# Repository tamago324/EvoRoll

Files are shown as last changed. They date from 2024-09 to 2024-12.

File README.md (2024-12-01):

# EvoRoll

左側を haqua34、右側を EvoRoll として使うことを想定している

> NOTE: KiCad 7 を使用しています

## [v1](v1/README.md)

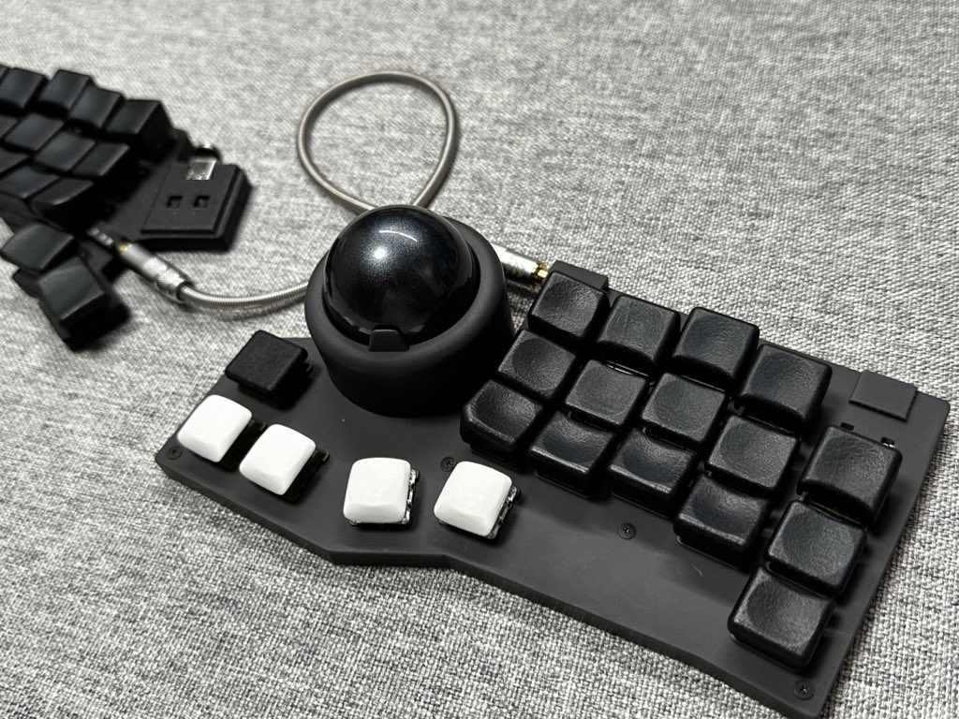
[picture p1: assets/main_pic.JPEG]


## [v2](v2/README.md)

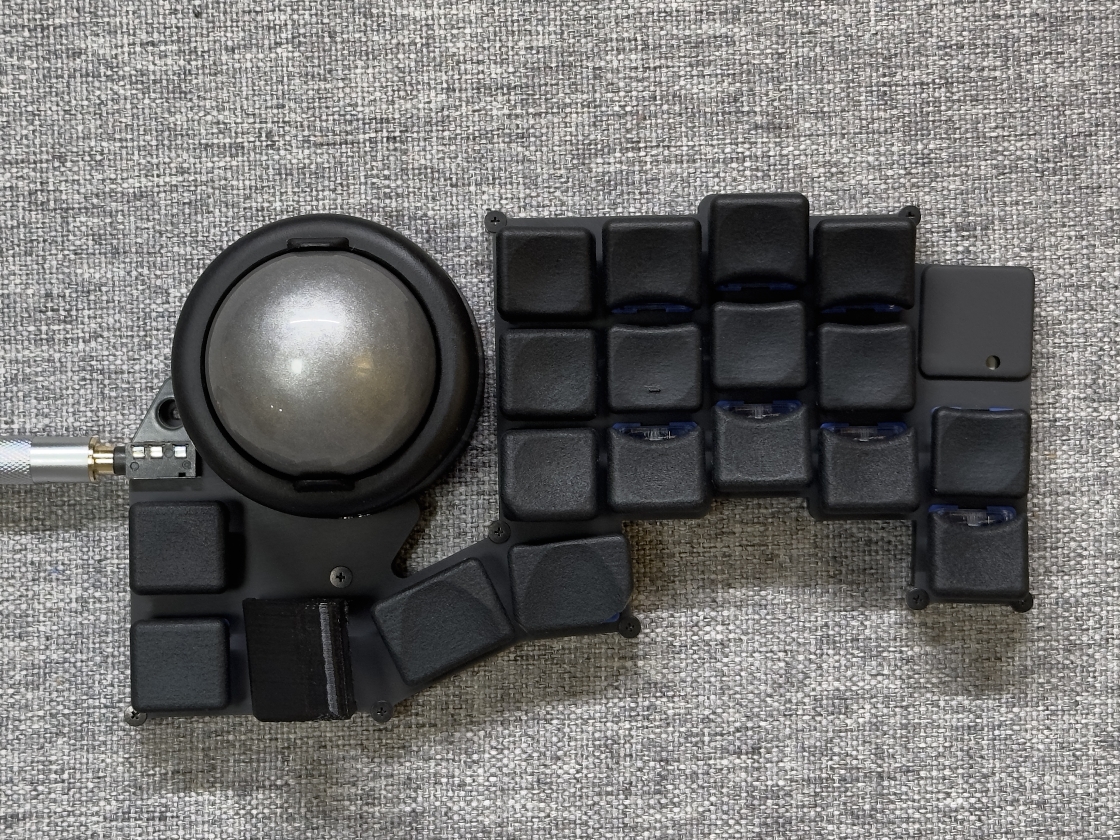
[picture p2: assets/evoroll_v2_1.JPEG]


## [v3](v3/README.md)



## [v4](v4/README.md)

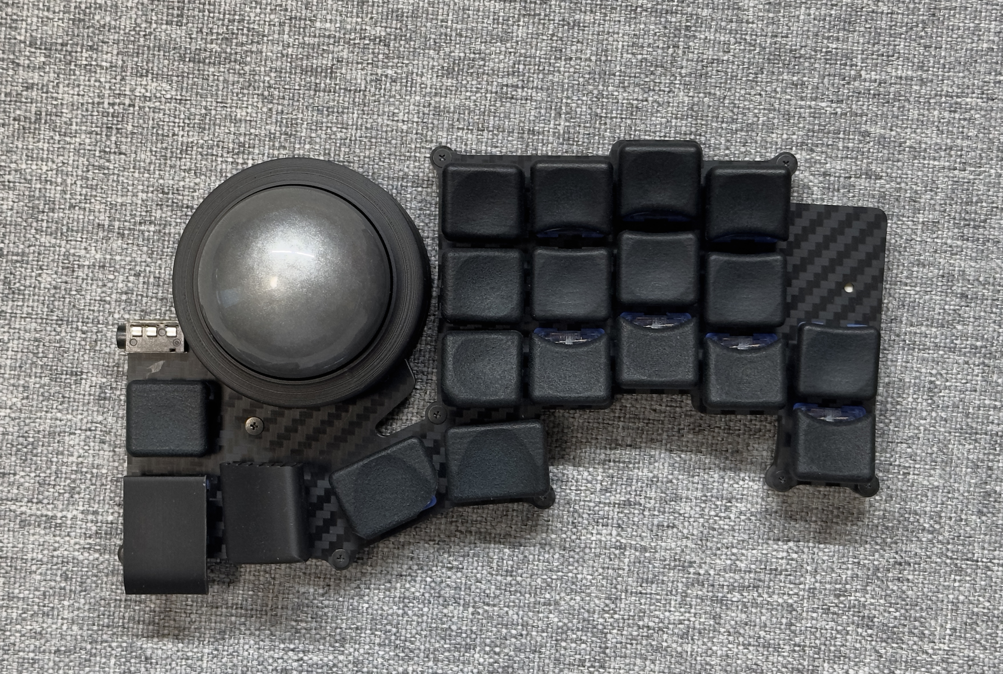
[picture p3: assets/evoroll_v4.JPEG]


## LICENSE

<br />この 作品 は <a rel="license" href="http://creativecommons.org/licenses/by-nc/4.0/">クリエイティブ・コモンズ 表示 - 非営利 4.0 国際 ライセンス</a>の下に提供されています。

> 表示 — あなたは 適切なクレジットを表示し、ライセンスへのリンクを提供し、変更があったらその旨を示さなければなりません。これらは合理的であればどのような方法で行っても構いませんが、許諾者があなたやあなたの利用行為を支持していると示唆するような方法は除きます。
>
> 非営利 — あなたは営利目的でこの資料を利用してはなりません。

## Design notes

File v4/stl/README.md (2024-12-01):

# EvoRoll で使用するケース

## 共通

共通で印刷するもの

* [common/top_case.stl](common/top_case.stl): トッププレート
* [common/bottom_case.stl](common/bottom_case.stl): ボトムプレート

## ボールケース

### ベアリングA (DDL-520ZZW52)

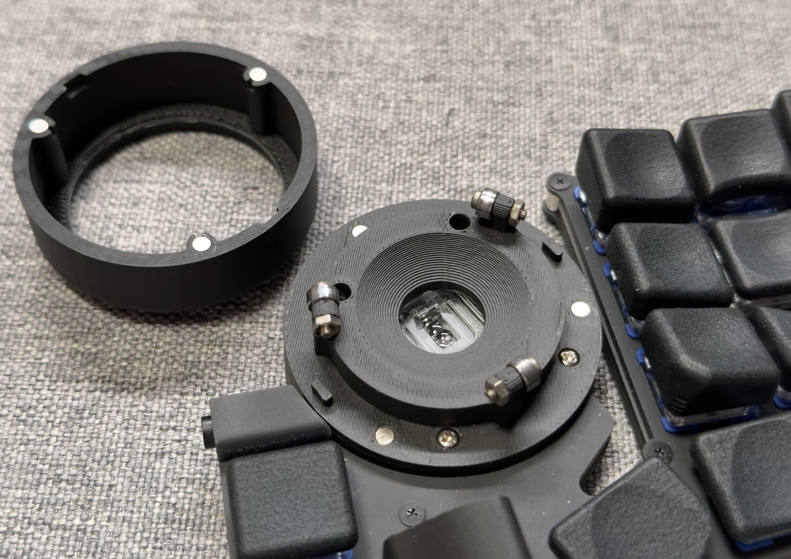
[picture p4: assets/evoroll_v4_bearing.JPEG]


印刷するもの

* [ballcase/bearing/ballcase_bottom_DDL-520ZZW52.stl](ballcase/bearing/ballcase_bottom_DDL-520ZZW52.stl)
* [ballcase/ballcase_top.stl](ballcase/ballcase_top.stl)

必要なもの

|名称|URL|説明|
|---|---|---|
|ベアリング|https://amzn.asia/d/8OED4Yl|DDL-520ZZW52 / 内径2mm、外形5mm、幅2.5mm|
|ねじ M2, 8mm||なべ小ねじならなんでもOK (頭径3.5mm、高さ1.3)|
|ナット M2|||
|タッピングネジ M2, 8mm|https://wilco.jp/products/F/FPP-N.html|ボトムプレートとボールケースを止めるために使用する。|
|磁石 3x2mm|https://amzn.asia/d/gBrgy0N|ケースに押し付けて入れる|

### ベアリングB (DDR-620ZZY52)

印刷するもの

* [ballcase/bearing/ballcase_bottom_DDR-620ZZY52.stl](ballcase/bearing/ballcase_bottom_DDR-620ZZY52.stl)
* [ballcase/ballcase_top.stl](ballcase/ballcase_top.stl)

必要なもの

|名称|URL|説明|
|---|---|---|
|ベアリング|https://www.monotaro.com/p/0953/7586/|DDR-620ZZY52 / 内径2mm、外形6mm、幅2.5mm|

ベアリング以外は、ベアリングAと同じ

### 静的ベアリング (Charybdis の [Static Bearing Mod](https://github.com/Bastardkb/Charybdis/blob/main/files/mods/readme.md#static-bearing-mod) のパーツを使用)

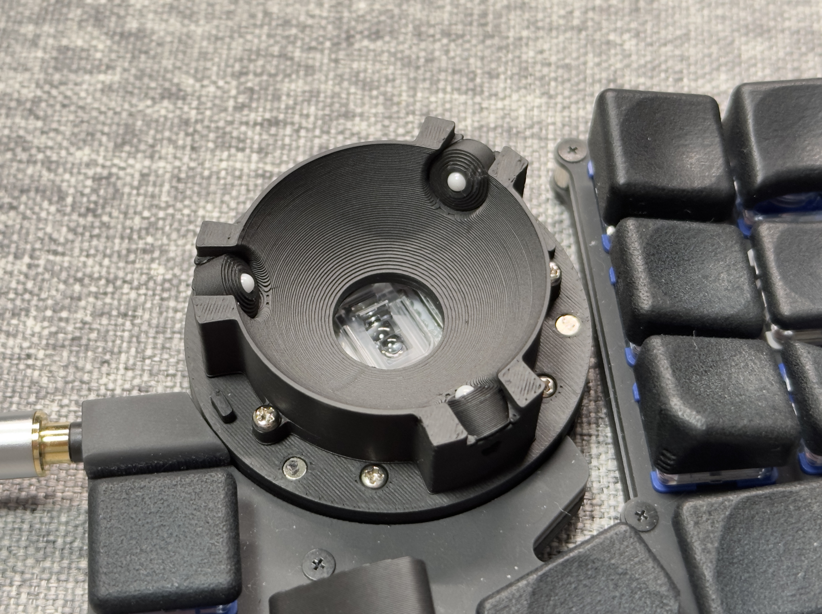
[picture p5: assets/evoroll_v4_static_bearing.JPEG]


印刷するもの

* [ballcase/static_bearing/ballcase_bottom_static_bearing_A.stl](ballcase/static_bearing/ballcase_bottom_static_bearing_A.stl)
* [ballcase/static_bearing/ballcase_bottom_static_bearing_B.stl](ballcase/static_bearing/ballcase_bottom_static_bearing_B.stl)
* [ballcase/static_bearing/printable_btu_2.5mm_ball.stl](ballcase/static_bearing/printable_btu_2.5mm_ball.stl)
  * [Charybdis の model](https://github.com/Bastardkb/Charybdis/blob/main/files/mods/static-bearing/printable_btu_2.5mm_ball.stl)と同じもの
* [ballcase/ballcase_top.stl](ballcase/ballcase_top.stl)

必要なもの

|名称|URL|説明|
|---|---|---|
|2.5mm ジルコニアボール|https://www.amazon.co.jp/dp/B07TJQN36D||
|タッピングネジ M2, 8mm|https://wilco.jp/products/F/FPP-N.html|ボトムプレートとボールケースAを止めるために使用する。|
|タッピングネジ M2, 5mm|https://wilco.jp/products/F/FPP-N.html|ボールケースAとボールケースBを止めるために使用する。|
|磁石 3x2mm|https://amzn.asia/d/gBrgy0N|ケースに押し付けて入れる|

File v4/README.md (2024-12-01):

# EvoRoll v4

左側を haqua34、右側を EvoRoll として使うことを想定している

> NOTE: KiCad 7 を使用しています



## v3 からの変更点

> NOTE: 基板はv3のものを使用

* ケース関連を家の3Dプリンタでも印刷できるようにした
* 支持球にジルコニアボールを使えるようにした

## 部品

| 部品 | リンク | 備考 |
| --- | --- | --- |
| PMW3360ブレークアウトボード | [monkeypad/pmw3360-breakout](https://github.com/monkeypad/pmw3360-breakout) | Booth で購入したら、ピンヘッダーもついていたけど、おそらく[これ](https://www.hirosugi-net.co.jp/shop/c/c12103211/) |
| ピンソケット 8ピン | https://www.hirosugi-net.co.jp/shop/c/c12111211/ | FSR-41085-08 / 8.5mmのものを使用する |
| スペーサー M2 5mm | https://www.hirosugi-net.co.jp/shop/c/c10141012/ | トッププレートとボトムプレートを止めるために使用する |
| ねじ M2 3mm | https://wilco.jp/products/F/FX-EB.html#page3 | トッププレートとボトムプレートを止めるために使用する |
| RP2040-Zero | | |
| ダイオード | | |
| chocソケット | | |
| TRRSソケット | | |

そのほかの部品については [stl](./stl/) フォルダを参照

## ケース

[stl](./stl/) フォルダを参照

## ファームウェア

https://github.com/tamago324/keyboard-firmwares/tree/master/keyboards/evoroll

## LICENSE

<br />この 作品 は <a rel="license" href="http://creativecommons.org/licenses/by-nc/4.0/">クリエイティブ・コモンズ 表示 - 非営利 4.0 国際 ライセンス</a>の下に提供されています。

> 表示 — あなたは 適切なクレジットを表示し、ライセンスへのリンクを提供し、変更があったらその旨を示さなければなりません。これらは合理的であればどのような方法で行っても構いませんが、許諾者があなたやあなたの利用行為を支持していると示唆するような方法は除きます。
>
> 非営利 — あなたは営利目的でこの資料を利用してはなりません。

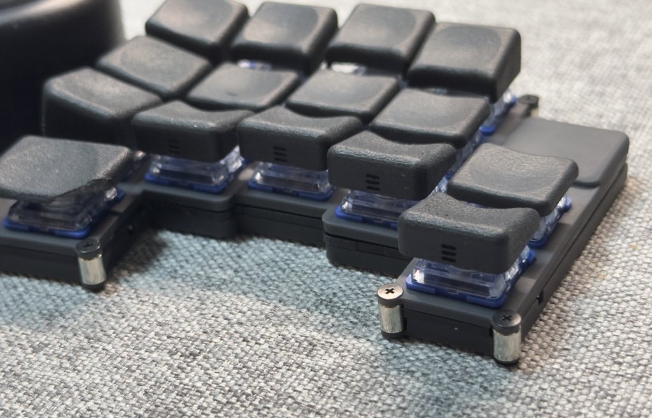
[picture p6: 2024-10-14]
assets/evoroll_v2_2.JPEG

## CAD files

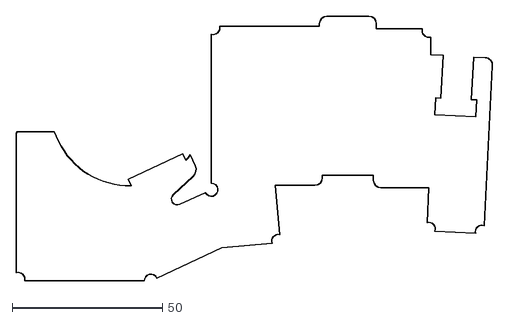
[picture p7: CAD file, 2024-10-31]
v4/dxf/evoroll_v3_edge.dxf
158.6 x 88.2

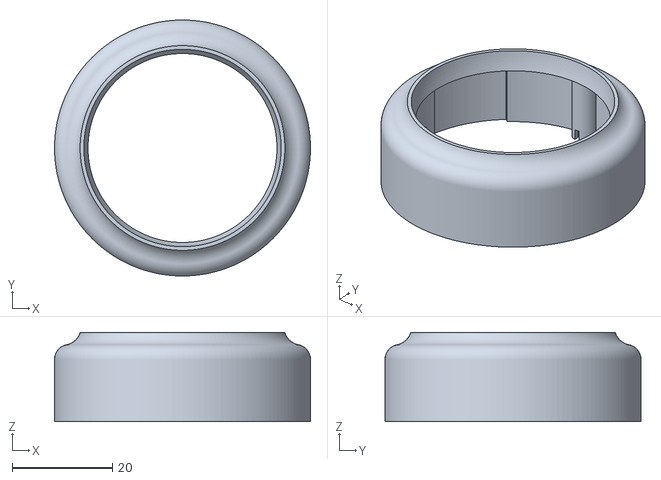
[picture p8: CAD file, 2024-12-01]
v4/stl/ballcase/ballcase_top.stl
51.0 x 51.0 x 17.7

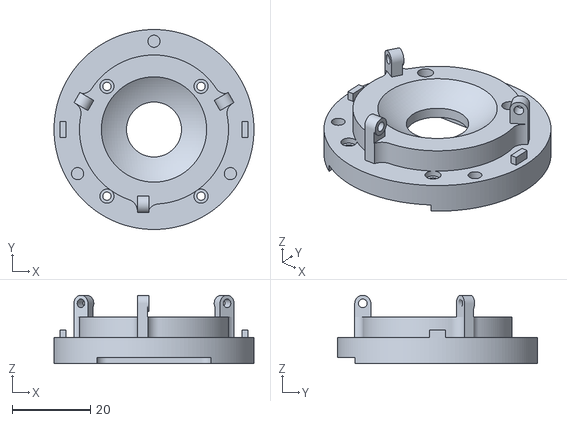
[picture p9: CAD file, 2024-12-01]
v4/stl/ballcase/bearing/ballcase_bottom_DDR-620ZZY52.stl
51.0 x 51.0 x 17.4

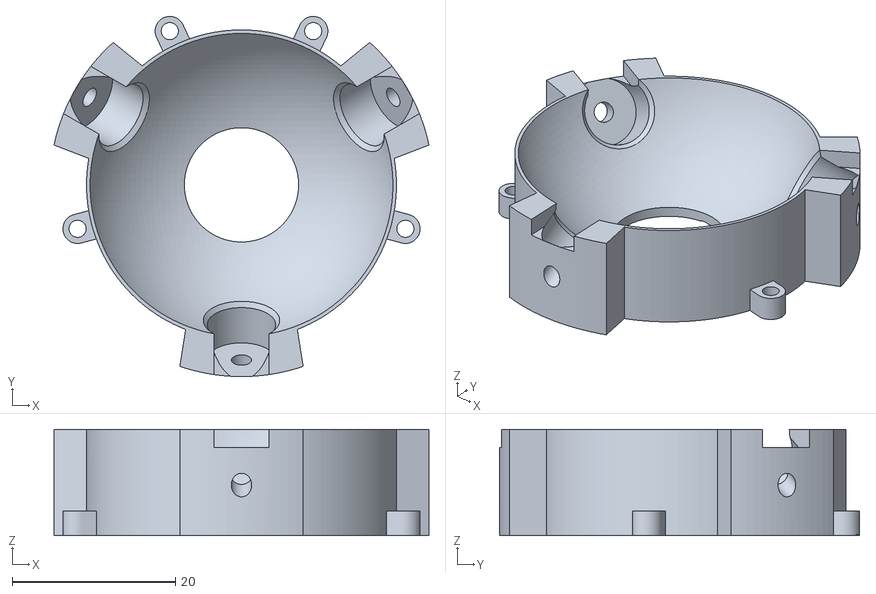
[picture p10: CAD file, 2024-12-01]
v4/stl/ballcase/static_bearing/ballcase_bottom_static_bearing_B.stl
46.0 x 44.2 x 13.0

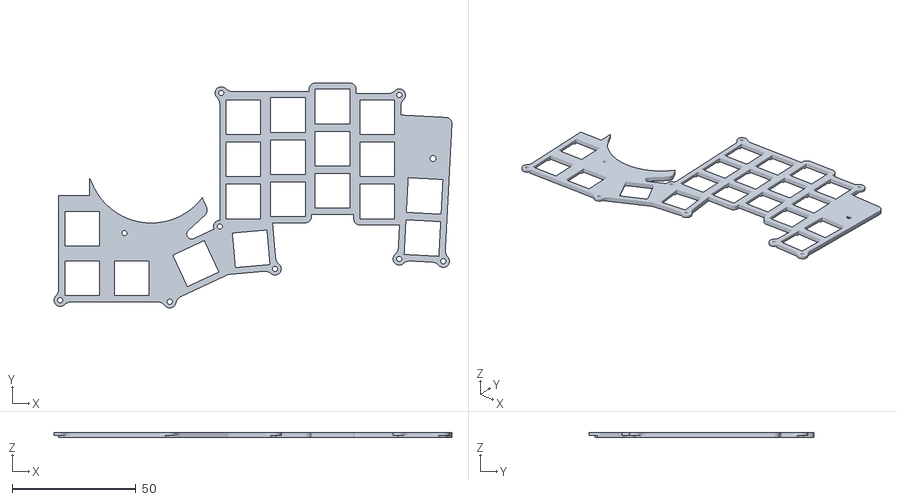
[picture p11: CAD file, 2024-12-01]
v4/stl/common/top_case.stl
160.5 x 90.7 x 2.20

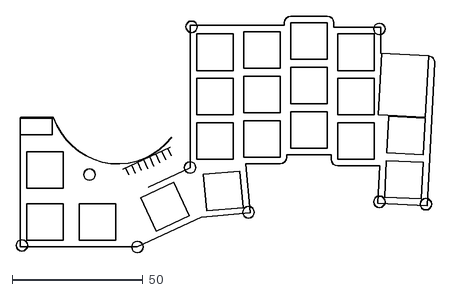
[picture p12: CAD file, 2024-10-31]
v4/dxf/evoroll_v3_support.dxf
160.2 x 90.4

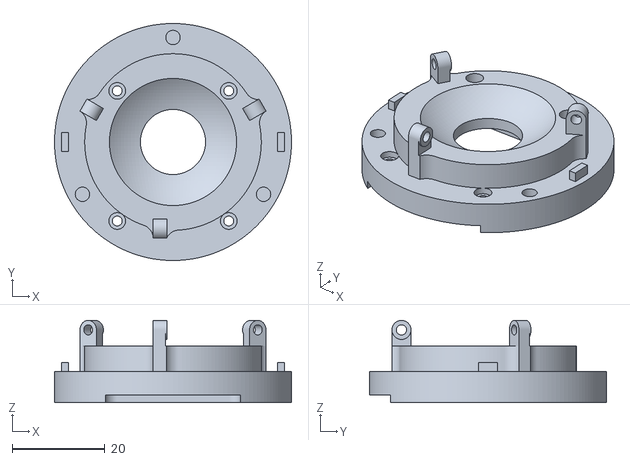
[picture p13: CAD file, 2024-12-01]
v4/stl/ballcase/bearing/ballcase_bottom_DDL-520ZZW52.stl
51.0 x 51.0 x 17.7

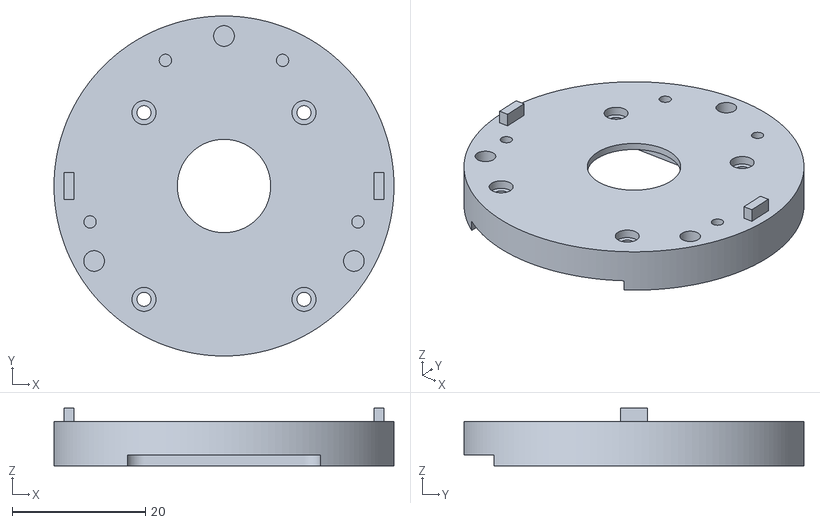
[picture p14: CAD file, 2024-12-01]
v4/stl/ballcase/static_bearing/ballcase_bottom_static_bearing_A.stl
51.0 x 51.0 x 8.65

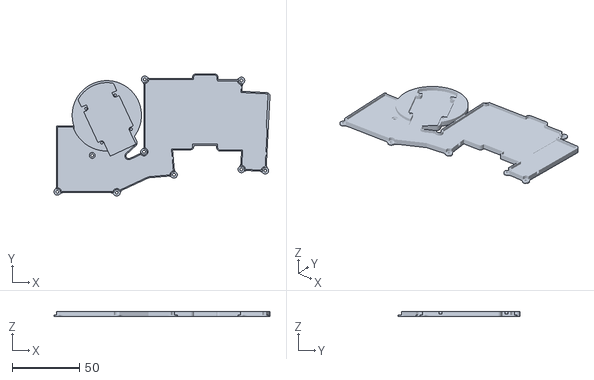
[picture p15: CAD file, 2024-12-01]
v4/stl/common/bottom_case.stl
160.5 x 90.7 x 3.80

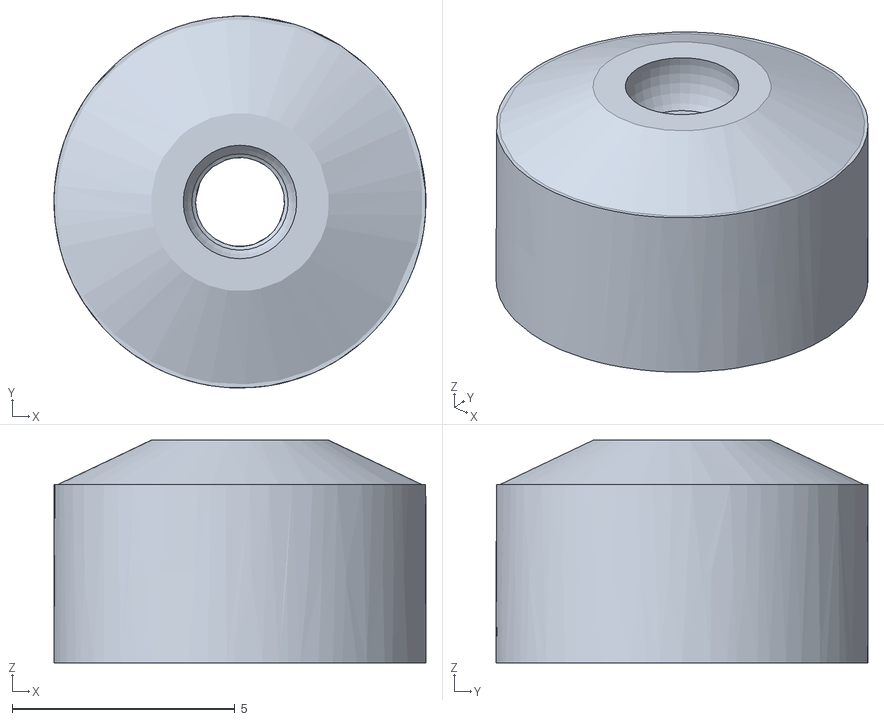
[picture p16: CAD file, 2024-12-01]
v4/stl/ballcase/static_bearing/printable_btu_2.5mm_ball.stl
8.35 x 8.35 x 5.00

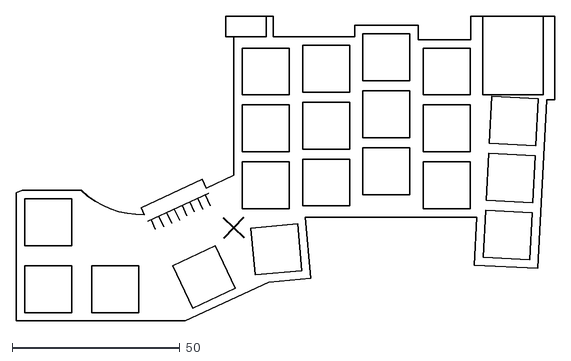
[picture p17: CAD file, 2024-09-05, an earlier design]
v1/dxf/pcb_support.dxf
160.7 x 91.0

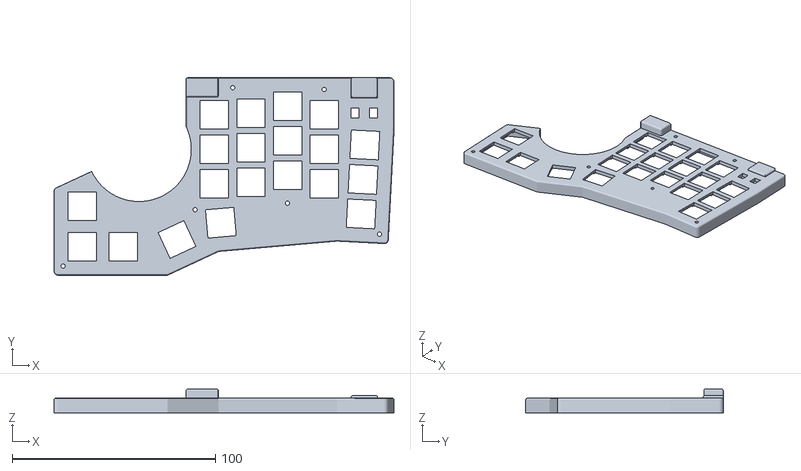
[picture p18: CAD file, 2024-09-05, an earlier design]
v1/stl/evoroll_v1_top_case.stl
167.3 x 97.2 x 11.8

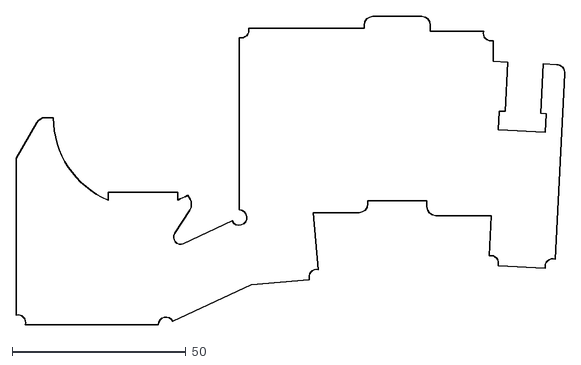
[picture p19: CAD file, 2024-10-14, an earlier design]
v2/dxf/evoroll_v2_edge.dxf
157.8 x 88.6

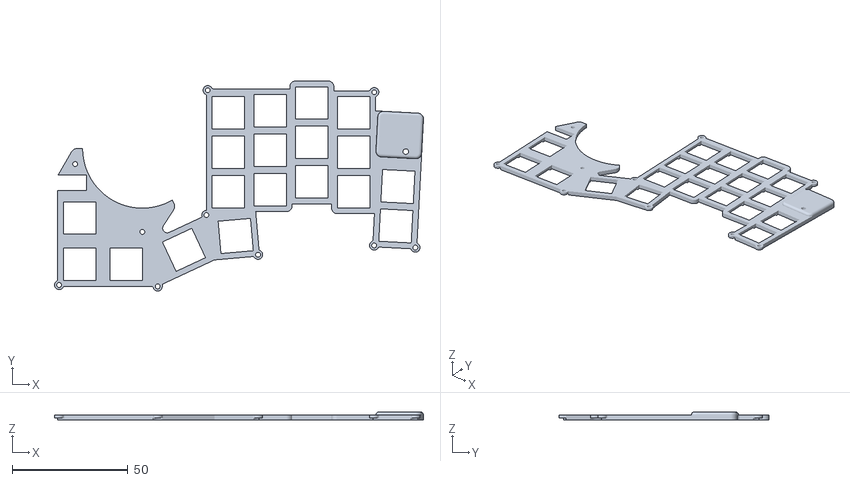
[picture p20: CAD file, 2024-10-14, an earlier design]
v2/stl/evoroll_v2_top_case.stl
159.2 x 90.6 x 3.50

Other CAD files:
v3/stl/evoroll_v3_bottom.stl
v1/dxf/pcb_edge.dxf
v1/stl/evoroll_v1_bottom_case.stl
v2/dxf/evoroll_v2_support.dxf
v2/stl/evoroll_v2_bottom_case.stl
v3/stl/evoroll_v3_top.stl

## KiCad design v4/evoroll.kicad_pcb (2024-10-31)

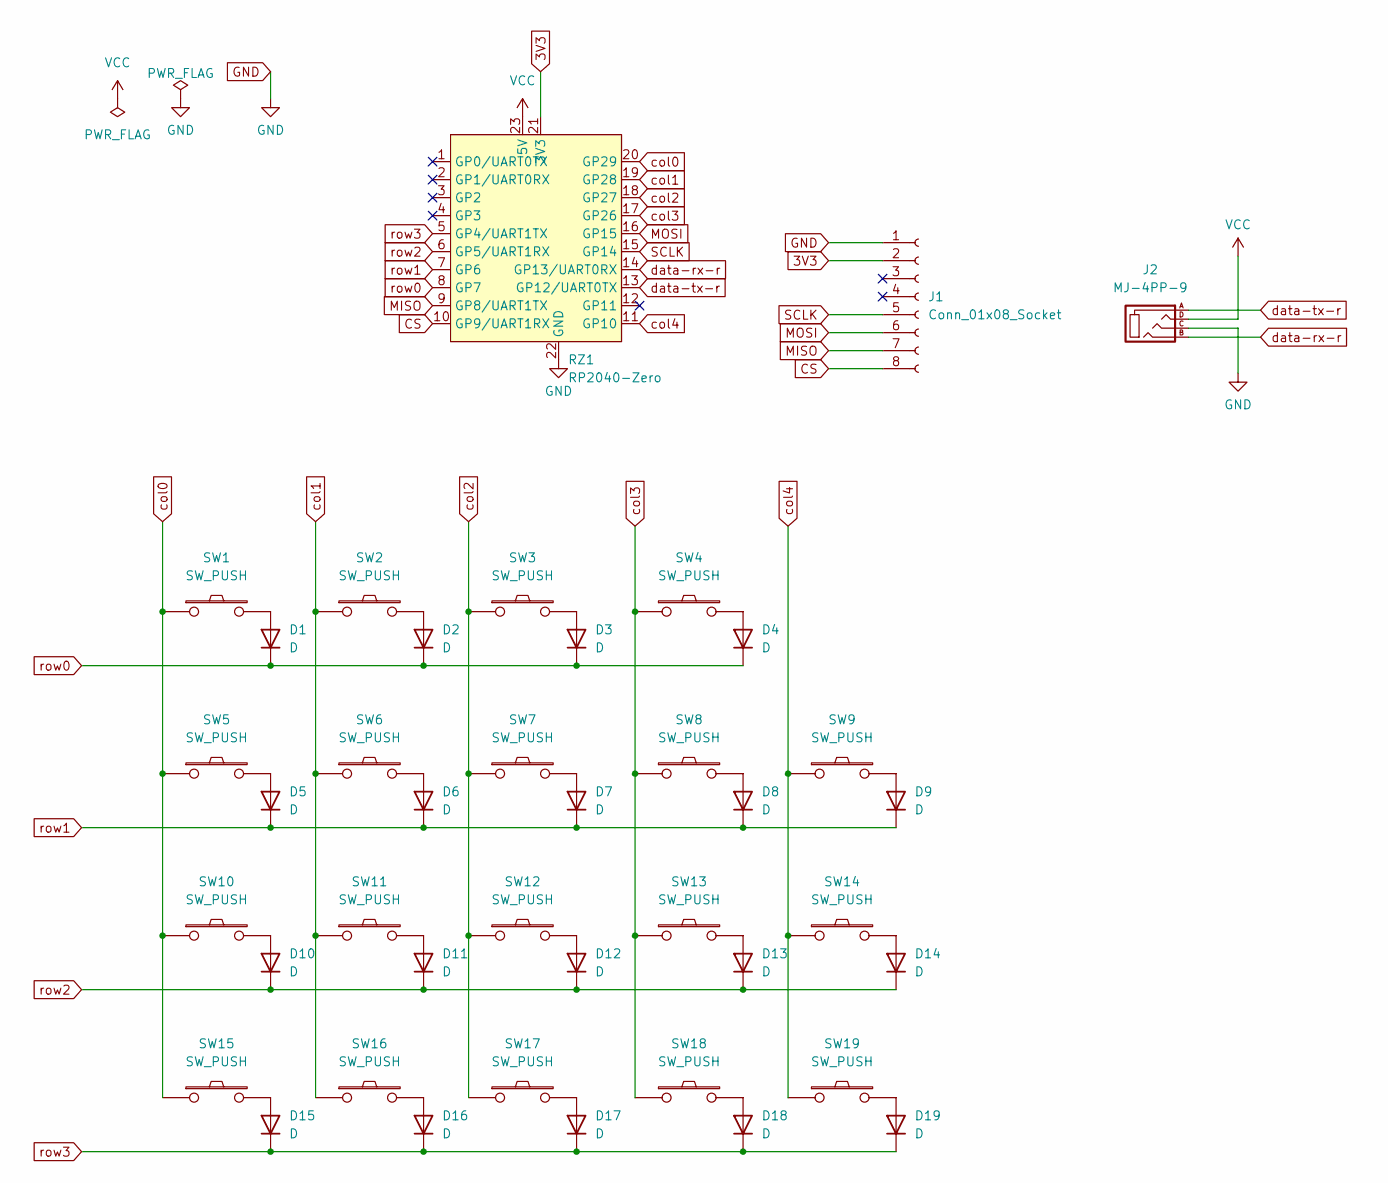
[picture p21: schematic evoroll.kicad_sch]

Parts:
D1, D2, D3, D4, D5, D6, D7, D8, D9, D10, D11, D12, D13, D14, D15, D16, D17, D18, D19: D; D3_SMD
J1: Conn_01x08_Socket; PinSocket_1x08_P2.54mm
J2: MJ-4PP-9
RZ1: RP2040-Zero
SW1, SW2, SW3, SW4, SW5, SW6, SW7, SW8, SW9, SW10, SW11, SW12, SW13, SW14, SW15, SW16, SW17, SW18, SW19: SW_PUSH; Kailh_socket_PG1350

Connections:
3V3: J1.2, RZ1.21 (3V3)
CS: J1.8, RZ1.10 (GP9/UART1RX)
GND: J1.1, J2.C, RZ1.22 (GND)
MISO: J1.7, RZ1.9 (GP8/UART1TX)
MOSI: J1.6, RZ1.16 (GP15)
unnamed: D1.2 (A), SW1.2
unnamed: D2.2 (A), SW2.2
unnamed: D3.2 (A), SW3.2
unnamed: D4.2 (A), SW4.2
unnamed: D5.2 (A), SW5.2
unnamed: D6.2 (A), SW6.2
unnamed: D7.2 (A), SW7.2
unnamed: D8.2 (A), SW8.2
unnamed: D9.2 (A), SW9.2
unnamed: D10.2 (A), SW10.2
unnamed: D11.2 (A), SW11.2
unnamed: D12.2 (A), SW12.2
unnamed: D13.2 (A), SW13.2
unnamed: D14.2 (A), SW14.2
unnamed: D15.2 (A), SW15.2
unnamed: D16.2 (A), SW16.2
unnamed: D17.2 (A), SW17.2
unnamed: D18.2 (A), SW18.2
unnamed: D19.2 (A), SW19.2
SCLK: J1.5, RZ1.15 (GP14)
VCC: J2.D, RZ1.23 (5V)
col0: RZ1.20 (GP29), SW1.1, SW5.1, SW10.1, SW15.1
col1: RZ1.19 (GP28), SW2.1, SW6.1, SW11.1, SW16.1
col2: RZ1.18 (GP27), SW3.1, SW7.1, SW12.1, SW17.1
col3: RZ1.17 (GP26), SW4.1, SW8.1, SW13.1, SW18.1
col4: RZ1.11 (GP10), SW9.1, SW14.1, SW19.1
data-rx-r: J2.B, RZ1.14 (GP13/UART0RX)
data-tx-r: J2.A, RZ1.13 (GP12/UART0TX)
row0: D1.1 (K), D2.1 (K), D3.1 (K), D4.1 (K), RZ1.8 (GP7)
row1: D5.1 (K), D6.1 (K), D7.1 (K), D8.1 (K), D9.1 (K), RZ1.7 (GP6)
row2: D10.1 (K), D11.1 (K), D12.1 (K), D13.1 (K), D14.1 (K), RZ1.6 (GP5/UART1RX)
row3: D15.1 (K), D16.1 (K), D17.1 (K), D18.1 (K), D19.1 (K), RZ1.5 (GP4/UART1TX)

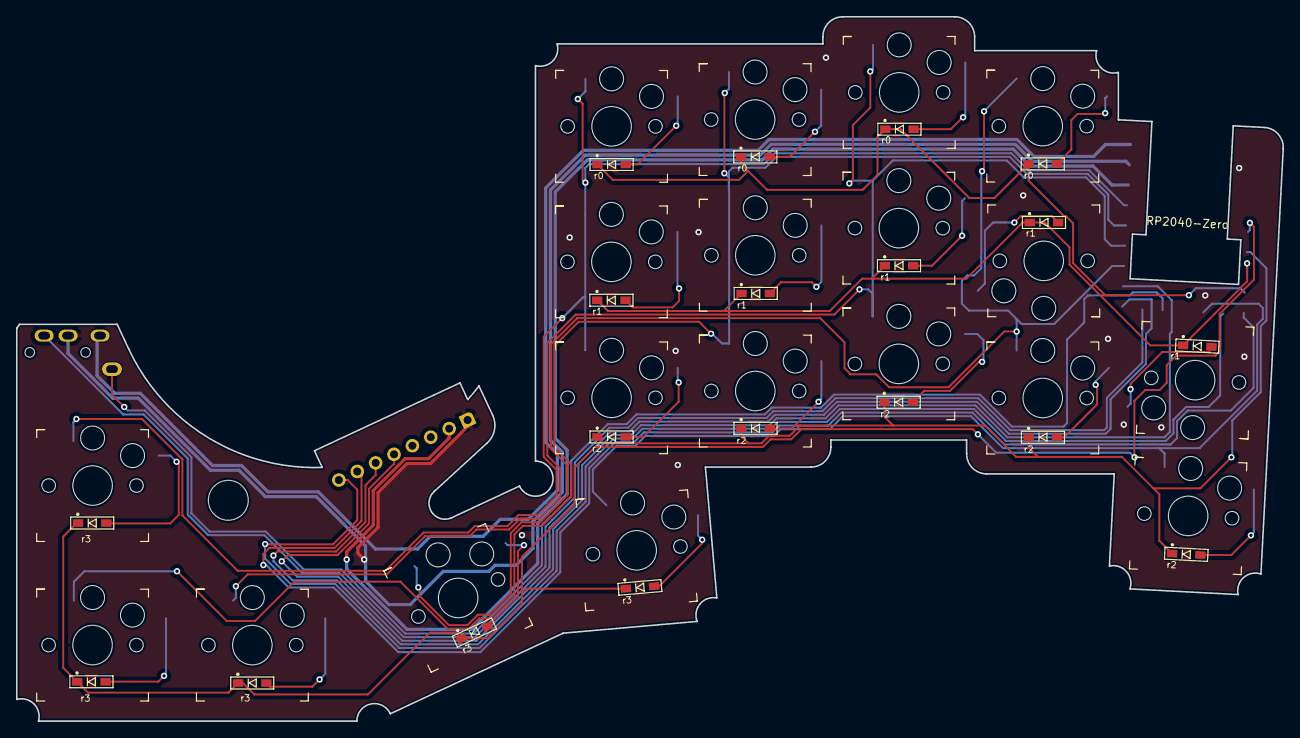
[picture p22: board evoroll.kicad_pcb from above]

Board: 2 copper layers, 158.6 x 88.2 mm, 42 parts (0 on the bottom side), 37 nets.

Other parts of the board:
Ref**: Val**; M2_HOLE_v2_5mm

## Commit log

2024-09-05 ファームウェアの場所を追加
2024-10-05 v1 フォルダに移動
    [evoroll-B_Cu.gbr, evoroll-B_Mask.gbr, evoroll-B_Silks.gbr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]
2024-10-05 README に v1 と v2 へのリンクを作成
2024-10-14 v2 追加
    [evoroll-B_Cu.gbr, evoroll-B_Mask.gbr, evoroll-B_Silks.gbr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]
2024-10-31 v3 追加
    [evoroll-B_Cu.gbr, evoroll-B_Mask.gbr, evoroll-B_Silks.gbr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]
2024-12-01 v4 追加
    [ballcase_bottom_DDL-520ZZW52.stl, ballcase_bottom_DDR-620ZZY52.stl, ballcase_bottom_static_bearing_A.stl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]

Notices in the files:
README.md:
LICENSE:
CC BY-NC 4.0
